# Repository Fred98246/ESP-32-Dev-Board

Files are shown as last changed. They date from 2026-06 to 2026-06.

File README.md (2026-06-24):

# Custom ESP32-S3-MINI-1 Development Board

## Overview
This repository contains the hardware design files for a custom ESP32-S3 4 layer development board. Built around the **ESP32-S3-MINI-1** module, this board is designed for flexible IoT development. 

The schematic and PCB layout were designed using **KiCad V6 E.D.A**.

**Schematic:**



**PCB:**




**Layers:**









**3D View:**



## Hardware Features
This development board includes:
* **Microcontroller:** ESP32-S3-MINI-1 (Wi-Fi & Bluetooth LE).
* **USB Interface:** USB Type-C receptacle with dedicated ESD protection (D3V3XA4B10LP).
* **Power Management:** 5V to 3.3V LDO regulator (TLV75801PDBV) with a dedicated power indicator LED.
* **Onboard Sensors & Outputs:**
  * **ENS210** Temperature and Humidity Sensor (connected via I2C).
  * **WS2812B** Addressable RGB LED for visual status feedback.
* **User Controls:** Physical `BOOT` and `RESET` tactile switches for easy flashing and debugging.
* **Expansion:** Two 22-pin headers breaking out GPIOs, I2C, UART, USB data lines, and power rails for easy breadboarding.

## Acknowledgements & Design Methodology
The design of this custom board was verified and optimized following the hardware design tutorials by **John Teel** at [Predictable Designs](https://predictabledesigns.com/). 

## Related Documents & Resources
For detailed specifications on the core components and reference designs, please consult the following official Espressif documentation:

* [ESP32-S3 Datasheet (PDF)](#)
* [ESP32-S3-MINI-1 & ESP32-S3-MINI-1U Datasheet (PDF)](#)
* [ESP32-S3-DevKitM-1 Schematic (PDF)](#)
* [ESP32-S3-DevKitM-1 PCB layout (PDF)](#)
* [ESP32-S3-DevKitM-1 Dimensions (PDF)](#)
* [ESP32-S3-DevKitM-1 Dimensions source file (DXF)](#) 

## Repository Structure
* `/Hardware` - KiCad project files (`.pro`, `.sch`, `.kicad_pcb`).
* `/Docs` - Exported schematics, BOM, and Gerber files for manufacturing.
* `/Firmware` - Example code for testing the WS2812B LED and ENS210 sensor.

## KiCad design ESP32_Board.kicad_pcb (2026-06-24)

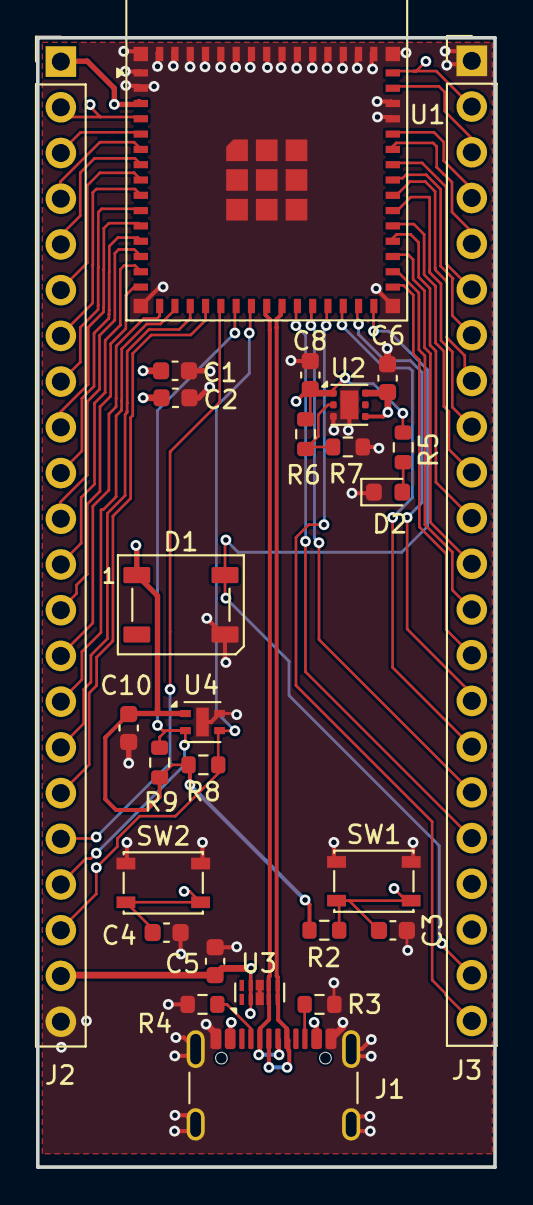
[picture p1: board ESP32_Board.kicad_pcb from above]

Board: 4 copper layers, 25.4 x 62.7 mm, 27 parts (0 on the bottom side), 47 nets.

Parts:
C1, C5, C6, C8: 10u; C_0603_1608Metric
C2, C3, C4: 0.1u; C_0603_1608Metric
C10: 0.1U; C_0603_1608Metric
D1: WS2812B; LED_WS2812B_PLCC4_5.0x5.0mm_P3.2mm
D2: RED; LED_0603_1608Metric
J1: USB_C_Receptacle_USB2.0_16P; USB_C_Receptacle_GCT_USB4105-xx-A_16P_TopMnt_Horizontal
J2, J3: Conn_01x22_Pin; PinHeader_1x22_P2.54mm_Vertical
R2, R8, R9: 10K; R_0603_1608Metric
R3, R4, R5: 5.1K; R_0603_1608Metric
R6: 1M; R_0603_1608Metric
R7: 200k; R_0603_1608Metric
SW1: RESET; SW_SPST_PTS810
SW2: BOOT; SW_SPST_PTS810
U1: ESP32-S3-MINI-1; ESP32-S2-MINI-1
U2: TLV75801PDRV; WSON-6-1EP_2x2mm_P0.65mm_EP1x1.6mm
U3: D3V3XA4B10LP; Diodes_UDFN-10_1.0x2.5mm_P0.5mm
U4: ENS210; AMS_QFN-4-1EP_2x2mm_P0.95mm_EP0.7x1.6mm

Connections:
+3.3V: C1.1, C2.1, C8.1, C10.1, D1.1 (VDD), J2.1, R2.1, R5.1, R6.1, R8.1, R9.1, U1.3 (3V3), U2.1 (OUT), U4.1 (VDD)
+5V: C5.2, C6.1, J1.A4 (VBUS), J1.A9 (VBUS), J1.B4 (VBUS), J1.B9 (VBUS), J2.21, U2.4 (EN), U2.6 (IN), U3.2, U3.9 (NC)
/BOOT: C4.2, J2.2, SW2.2, U1.4 (IO0)
/EN: C3.2, J3.2, R2.2, SW1.2, U1.45 (EN)
/GPIO1: J2.3, U1.5 (IO1)
/GPIO2: J2.4, U1.6 (IO2)
/GPIO3: J2.5, U1.7 (IO3)
/GPIO4: J2.6, U1.8 (IO4)
/GPIO5: J2.7, U1.9 (IO5)
/GPIO6: J2.8, U1.10 (IO6)
/GPIO7: J2.9, U1.11 (IO7)
/GPIO8: J2.10, U1.12 (IO8)
/GPIO9: J2.11, U1.13 (IO9)
/GPIO10: J2.12, U1.14 (IO10)
/GPIO11: J2.13, U1.15 (IO11)
/GPIO12: J2.14, U1.16 (IO12)
/GPIO13: J2.15, U1.17 (IO13)
/GPIO14: J2.16, U1.18 (IO14)
/GPIO15: J2.17, U1.19 (IO15)
/GPIO16: J2.18, U1.20 (IO16)
/GPIO21: J3.18, U1.25 (IO21)
/GPIO26: J3.17, U1.26 (IO26)
/GPIO33: J3.16, U1.28 (IO33)
/GPIO34: J3.15, U1.29 (IO34)
/GPIO35: J3.14, U1.31 (IO35)
/GPIO36: J3.13, U1.32 (IO36)
/GPIO37: J3.12, U1.33 (IO37)
/GPIO38: J3.11, U1.34 (IO38)
/GPIO39: J3.10, U1.35 (IO39)
/GPIO40: J3.9, U1.36 (IO40)
/GPIO41: J3.8, U1.37 (IO41)
/GPIO42: J3.7, U1.38 (IO42)
/GPIO45: J3.4, U1.41 (IO45)
/GPIO46: J3.3, U1.44 (IO46)
/GPIO47: J3.22, U1.27 (IO47)
/GPIO48: D1.4 (DIN), J3.21, U1.30 (IO48)
/I2C_SCL: J2.19, R9.2, U1.21 (IO17), U4.2 (SCL)
/I2C_SDA: J2.20, R8.2, U1.22 (IO18), U4.3 (SDA)
/LED_POWER: D2.2 (A), R5.2
/RXD: J3.5, U1.40 (RXD0)
/TXD: J3.6, U1.39 (TXD0)
/USB_N: J1.A7 (D-), J1.B7 (D-), U1.23 (USB_D-), U3.4, U3.7 (NC)
/USB_P: J1.A6 (D+), J1.B6 (D+), U1.24 (USB_D+), U3.5, U3.6 (NC)
GND: C1.2, C2.2, C3.1, C4.1, C5.1, C6.2, C8.2, C10.2, D1.3 (VSS), D2.1 (K), J1.A1 (GND), J1.A12 (GND), J1.B1 (GND), J1.B12 (GND), J1.S1 (SHIELD), J2.22, J3.1, R3.2, R4.2, R7.2, SW1.1, SW2.1, U1.1 (GND), U1.2 (GND), U1.42 (GND), U1.43 (GND), U1.46 (GND), U1.47 (GND), U1.48 (GND), U1.49 (GND), U1.50 (GND), U1.51 (GND), U1.52 (GND), U1.53 (GND), U1.54 (GND), U1.55 (GND), U1.56 (GND), U1.57 (GND), U1.58 (GND), U1.59 (GND), U1.60 (GND), U1.61 (GND), U1.62 (GND), U1.63 (GND), U1.64 (GND), U1.65 (GND), U2.3 (GND), U2.7 (GND), U3.3 (VSS), U3.8 (VSS), U4.4 (GND), U4.5 (GND)
unnamed: J1.A5 (CC1), R4.1
unnamed: J1.B5 (CC2), R3.1
unnamed: R6.2, R7.1, U2.2 (FB)
